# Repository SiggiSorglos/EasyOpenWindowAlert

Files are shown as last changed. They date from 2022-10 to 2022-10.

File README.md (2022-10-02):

# EasyOpenWindowAlert
energy saving device: sounding alarm when a window is open for more than 5 minutes.

This project contains the code and the schematic for a device to save energy.
A lot of energy is wasted by left open windows during the winter. 
This can be avoided by alarming the user that the window is still open.

A simple device will sound an alarm if a window is open for more than 5 minutes.
The open window is detected with a reed switch.
The reed switch is toggled by a magnet mounted to the window.

steps to get started:
1. program an ATtiny85 in the Arduino IDE with the code
2. build the simple electronic around it (see schematic) and plug in the ATtiny85 to the socket.
3. Optional: build a housing i. e. with a 3D printer (see openscad files)
4. Mount the device next to a window and the magnet on the window. 

Theory of operation:
As long as the window is closed, the reed switch is closed and the ATtiny85 sleeps. Therefore the current consumption is very low.
The circuit should run on 2 AAA Batteries for > 2 years.
When the window is opened the switch opens. The LED lights up for 2 seconds to indicate that the "window opened" event was detected.
To indicate that the timer is running, the LED flashes every 4 seconds.
If the window is open for 5 Minutes, a sound (three beeps) will alarm the user to close the window.
If the window is not closed, the alarm will repeated after 5 Minutes.
If the window is closed, or the alarm was repeated three times, the ATtiny85 will go to sleep again.

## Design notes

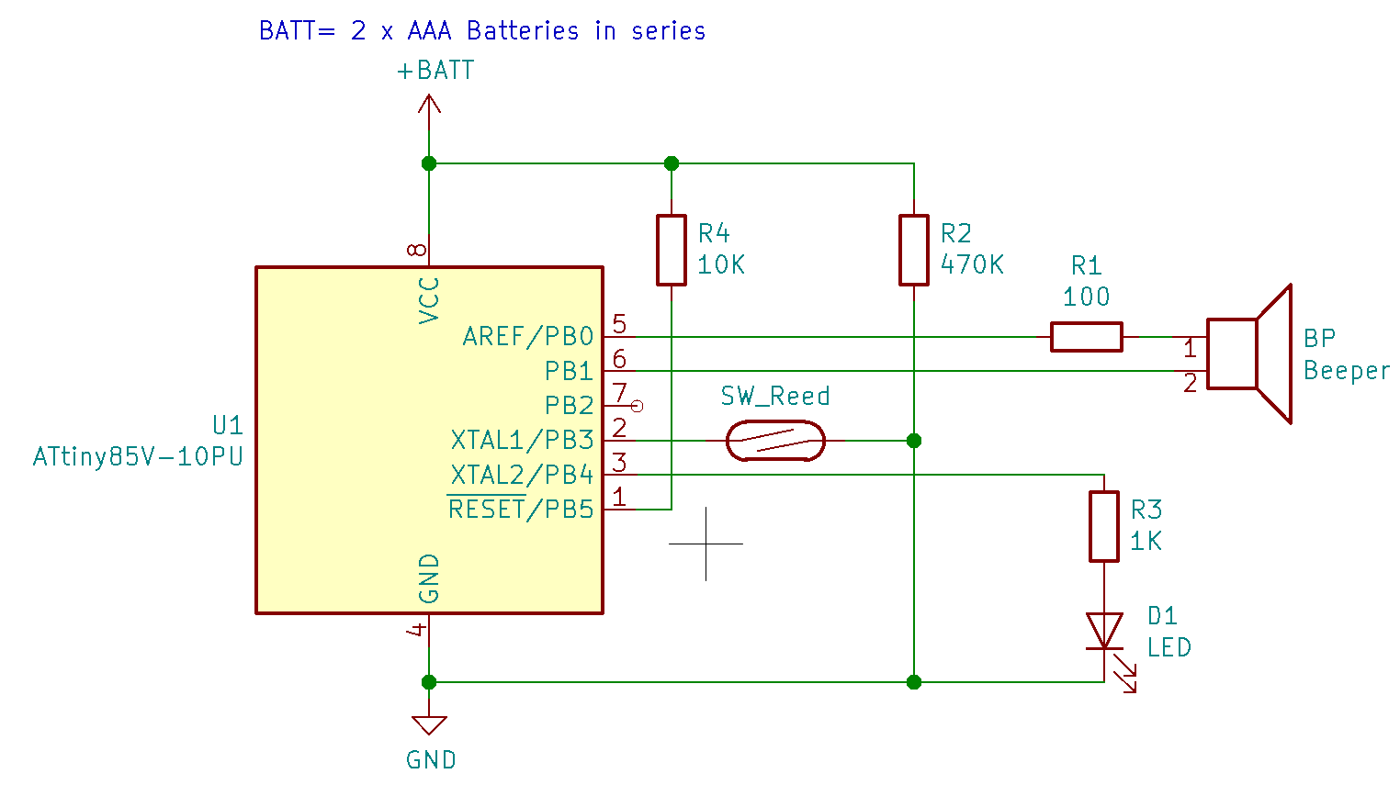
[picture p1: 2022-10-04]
EOWA M1.png

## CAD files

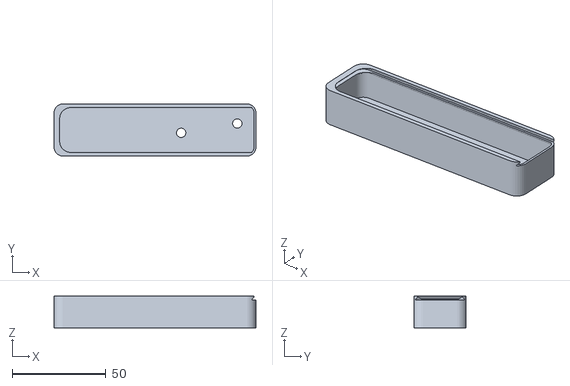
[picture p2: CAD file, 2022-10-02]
EOWA M1 Box long.stl
108.0 x 27.9 x 17.0

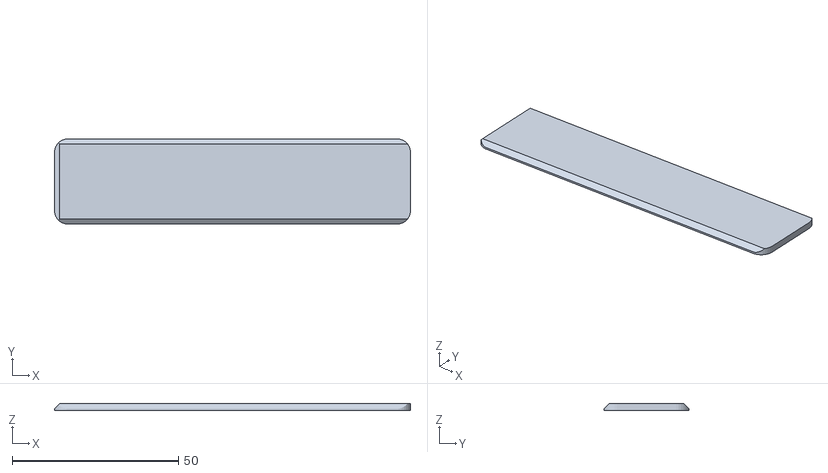
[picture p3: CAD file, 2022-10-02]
EOWA M1 Lid long.stl
107.0 x 25.6 x 2.00

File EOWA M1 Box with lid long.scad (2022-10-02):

itemsShown="box"; // [both,box,lid]
boxLength=108;
boxWidth=28;
boxHeight=17;
cornerRadius=5;
wallThickness=1;
bottomThickness=1;
lidThickness=2;
lidClearance=0.4;
lidEdgeThickness=0.5;
// Notch in the lid
withNotch=false;//true;//[true:false]

/* [Global] */
if (itemsShown=="box") Box();
if (itemsShown=="lid") showLid();
if (itemsShown=="both"){Box();showLid();}


module Box() {
    difference () {
        showBox();
        // hole for for switch
        translate([15+53,12.5,-1]) cylinder (h=10, d=5, $fn=20);
        // hole for buzzer
        translate([46+53,17,-1]) cylinder (h=10, d=5, $fn=20);
    }
}


module showLid(){
	translate ([0, -2*wallThickness, 0]) 
	roundBoxLid(l=boxLength-wallThickness,
				w=boxWidth-2*wallThickness-lidClearance,
				h=lidThickness,
				et=lidEdgeThickness,
				r=cornerRadius-wallThickness,
				notch=withNotch);
}

module showBox(){
	round_box(l=boxLength,
			  w=boxWidth,
			  h=boxHeight,
			  bt=bottomThickness,
			  wt=wallThickness,
			  lt=lidThickness,
			  r=cornerRadius);
}

module round_box(l=40,w=30,h=30,bt=2,wt=2,lt=2,r=5,){
	difference() { 
		round_cube(l=l,w=w,h=h-lt,r=r);
		translate ([wt, wt, bt]) 
		round_cube(l=l-wt*2,w=w-wt*2,h=h,r=r-wt);
	}
	//use two box rims. one to make a slope to support the lid
	roundBoxRim();
	translate ([0, 0, -wt*2]) roundBoxRim();
}

module roundBoxRim(l=boxLength,
				   w=boxWidth,
				   h=boxHeight,
				   et=lidEdgeThickness,
				   r=cornerRadius,
				   wt=wallThickness,
				   lt=lidThickness){
	difference() { 
		translate ([0, 0, h-lt]) 
		round_cube(l=l,w=w,h=lt,r=r);
		translate ([wt+lt,wt+lt-et*2,h-lt-0.1]) 
		round_cube(l=l*2,w=w-2*(wt+lt)+4*et,h=lt+0.2,r=r-wt+lt);

		//subtract out a lid to make the ledge
		translate ([wt, w-wt, h-lt-0.1])
		roundBoxLid(l=l*2,w=w-2*wt,h=lt+0.1,wt=wt,t=lt,et=0.5,r=r-wt,notch=false);
	}
}

module roundBoxLid(l=40,w=30,h=3,wt=2,t=2,et=0.5,r=5,notch=true){
	translate ([l, 0, 0]) 
	rotate (a = [0, 0, 180]) 
	difference(){
		round_cube(l=l,w=w,h=h,r=r);

		translate ([-1, 0, et]) rotate (a = [45, 0, 0])  cube (size = [l+2, h*2, h*2]); 
		translate ([-1, w, et]) rotate (a = [45, 0, 0])  cube (size = [l+2, h*2, h*2]); 
		translate ([l, -1, et]) rotate (a = [45, 0, 90]) cube (size = [w+2, h*2, h*2]); 
		if (notch==true){
			translate([2,w/2,h+0.001]) thumbNotch(10/2,72,t);
		}
	}
}

module thumbNotch(
	thumbR=12/2,
	angle=72,
	notchHeight=2){

	size=10*thumbR;

	rotate([0,0,90])
	difference(){
		translate([0,
					(thumbR*sin(angle)-notchHeight)/tan(angle),
					 thumbR*sin(angle)-notchHeight])
		rotate([angle,0,0])
		cylinder(r=thumbR,h=size,$fn=30);

		translate([-size,-size,0])
		cube(size*2);
	}
}

module round_cube(l=40,w=30,h=20,r=5,$fn=30){
	hull(){ 
		translate ([r, r, 0]) cylinder (h = h, r=r);
		translate ([r, w-r, 0]) cylinder (h = h, r=r);
		translate ([l-r,w-r, 0]) cylinder (h = h, r=r);
		translate ([l-r, r, 0]) cylinder (h = h, r=r);
	}
}

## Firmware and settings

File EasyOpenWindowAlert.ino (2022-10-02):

/*
   This file is part of EasyOpenWindowAlert Arduino project for an ATtiny85 Energy saver device.
   It soinds an alert when the Window (Reed Conact) ist open for more  than 5 minutes
   Copyright (c) 2022 by Siggi Sorglos (siggi.sorglos2@gmx.de)
   Permission is hereby granted, free of charge, to any person obtaining a copy
   of this software and associated documentation files (the "Software"), to deal
   in the Software without restriction, including without limitation the rights
   to use, copy, modify, merge, publish, distribute, sublicense, and/or sell
   copies of the Software, and to permit persons to whom the Software is
   furnished to do so, subject to the following conditions:
   The above copyright notice and this permission notice shall be included in all
   copies or substantial portions of the Software.
   THE SOFTWARE IS PROVIDED "AS IS", WITHOUT WARRANTY OF ANY KIND, EXPRESS OR
   IMPLIED, INCLUDING BUT NOT LIMITED TO THE WARRANTIES OF MERCHANTABILITY,
   FITNESS FOR A PARTICULAR PURPOSE AND NONINFRINGEMENT. IN NO EVENT SHALL THE
   AUTHORS OR COPYRIGHT HOLDERS BE LIABLE FOR ANY CLAIM, DAMAGES OR OTHER
   LIABILITY, WHETHER IN AN ACTION OF CONTRACT, TORT OR OTHERWISE, ARISING FROM,
   OUT OF OR IN CONNECTION WITH THE SOFTWARE OR THE USE OR OTHER DEALINGS
   IN THE SOFTWARE.
*/

/*
 * Attiny85 PINS
 *                ____
 * RESET        -|*   |- 5V
 * SWITCH (PB3) -|    |- (PB2) NOT_USED
 * LED    (PB4) -|    |- (PB1) BEEP_MINUS
 * GND          -|____|- (PB0) BEEP_PLUS
 */


#include <avr/interrupt.h> // needed for the additional interrupt
#include <avr/sleep.h>     // Sleep Modes
#include <avr/io.h>
#include <avr/power.h>
#include "TimerFreeTone.h" // see https://forum.arduino.cc/t/timerfreetone-library-v1-5-play-tones-without-timers-and-therefore-no-conflicts/229448

#define WD_TIMEOUT 4 // watchdog timeout 4 sec

// application parameters
#define DELAY_ALERT 5 // delay between window opening and start of alert in minutes
#define NUM_REPEAT 3  // max. 3 repetitions of the alert.
#define DURATION_ALERT 3 // duration of the alert in seconds

#define NUM_WD (60 * DELAY_ALERT) / WD_TIMEOUT // number of watchdog cycles before alert 

#define   F_CPU   1000000UL  // clock rate to make delay(), millis(), micros() work correct

// hardware configuration constants
#define LED PB4
#define SWITCH PB3
#define BEEP_PLUS PB0
#define BEEP_MINUS PB1

#define adc_disable() (ADCSRA &= ~(1<<ADEN)) // disable ADC (before power-off)
#define adc_enable()  (ADCSRA |=  (1<<ADEN)) // re-enable ADC

#define WINDOW_OPEN digitalRead(SWITCH) // window open / input high => digitalRead(SWITCH), window open / input low => !digitalRead(SWITCH)
// interrupt routines
ISR (PCINT0_vect){ // switch interrupt
  // pin change wake up interrupt, do nothing
}

ISR(WDT_vect) { // warchdog interrupt
  // wdt wake up interrupt, do nothing
}                  

// helper functions
void powerDown() {
  set_sleep_mode(SLEEP_MODE_PWR_DOWN);
  cli();
  sleep_enable();
  sleep_bod_disable();
  sei();
  sleep_cpu();
  sleep_disable();
  sei();
}

void watchdogOff(){
  cli();
  asm("WDR");
  MCUSR &= ~ bit (WDRF);
  WDTCR |= bit (WDCE) | bit (WDE);
  WDTCR = 0x00;
  sei();
}

void configurePinChangeInterrupt() {
  // configure pin change interrupt
  PCMSK  |= bit (PCINT3);  // want pin 3
  GIFR   |= bit (PCIF);    // clear any outstanding interrupts
  GIMSK  |= bit (PCIE);    // enable pin change interrupts
  sei();  // enable interrupts
}

// setup
void setup() {
  //clock_prescale_set(clock_div_8);    // Prescaler 8 => CPU-Clock = 1 MHz, Prescaler 256 => CPU-CLock = 31,25 kHz
  // put your setup code here, to run once:
  pinMode(SWITCH, INPUT);  //  no external pullup / pulldown => pinMode(SWITCH, INPUT_PULLUP);
  pinMode(BEEP_PLUS, OUTPUT);
  pinMode(BEEP_MINUS, OUTPUT);
  pinMode(LED, OUTPUT);

  // short blink at startup to inidicate readyness.
  digitalWrite(LED, HIGH);
  delay (200);
  digitalWrite(LED, LOW);
  delay (200);
}

// main loop
void loop() {
  // sleep and use pin change interrupt to wake up
  // double blink before going to sleep
  for (int i = 0; i<2; i++) {
    digitalWrite(LED, HIGH);
    delay(200);
    digitalWrite(LED, LOW);
    delay(200);
  }
  adc_disable(); 
  configurePinChangeInterrupt(); 
  powerDown();             
  GIMSK  &= ~bit (PCIE);      // disable pin change interrupt. do not wake up by pin change if waiting for watchdog is active
  //cli();                    // wake up here, disable interrupts 
  delay (100);                // avoid bouncing contacts
  
  digitalWrite(LED, HIGH);
  if (WINDOW_OPEN) 
    delay(2000);
  else
    delay(500);
  digitalWrite(LED, LOW);
  
  for (int repeat = 0; repeat < NUM_REPEAT; repeat++) {  // repeat alert max. NUM_REPEAT times
    // delay alert in sleeping mode with watchdog timeout interrupt
    for (int num_wd_cycle = 0; num_wd_cycle < NUM_WD; num_wd_cycle++) { // number of times the watchdog timer delays the alert   
      if (WINDOW_OPEN) {
        // flash LED
        digitalWrite(LED, HIGH);
        delay (100);
        digitalWrite(LED, LOW);
        //sei();                          // enable ISR
        WDTCR = bit (WDIE) | bit (WDP3); // | bit (WDP0);  // watchdog time 4s
        MCUCR = bit (SE) + bit (SM1);   // select power down mode
        sleep_cpu();                    // goto sleep
        //cli();                          //wake up here, disable interrupts
      }
      else break;
    }
      
    if (WINDOW_OPEN) { 
      //for (int freq = 2000; freq < 3000; freq += 10) {
      for (int i = 0; i < DURATION_ALERT; i++) { 
        if (WINDOW_OPEN) {
          // Alarm on + blink LED
          digitalWrite(LED, HIGH);
          TimerFreeTone(BEEP_PLUS, BEEP_MINUS, 2000, 500);
          digitalWrite(LED, LOW);
          delay (500);
        }
        else break; 
      }
    }
    else break;
  }
  watchdogOff();
}

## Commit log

2022-10-02 initial commit
    .ino file for Arduino IDE
2022-10-02 initial commit
    picture of schematic
2022-10-02 Open Scad and stl files for the housing
    housing for electronics and 2 x AAA Battery holder
    [EOWA M1 Box long.stl, EOWA M1 Box with lid long.scad, EOWA M1 Lid long.stl]
2022-10-04 add pullup resistor to schematic
